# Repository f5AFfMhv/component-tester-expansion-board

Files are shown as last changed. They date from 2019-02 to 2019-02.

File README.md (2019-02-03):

# Electronic component tester expansion board

This is PCB expansion board for one of many variants of cheap electronic component testers (see picture).
<br>
[Schematic Rev A](https://github.com/f5AFfMhv/component-tester-expansion-board/raw/master/Rev%20A/component_tester_adapter.pdf)
<br>
[Schematic Rev B](https://github.com/f5AFfMhv/component-tester-expansion-board/raw/master/Rev%20B/schematic.pdf)
<br>
[BOM Rev B](https://raw.githubusercontent.com/f5AFfMhv/component-tester-expansion-board/master/Rev%20B/component_tester_adapter.csv)

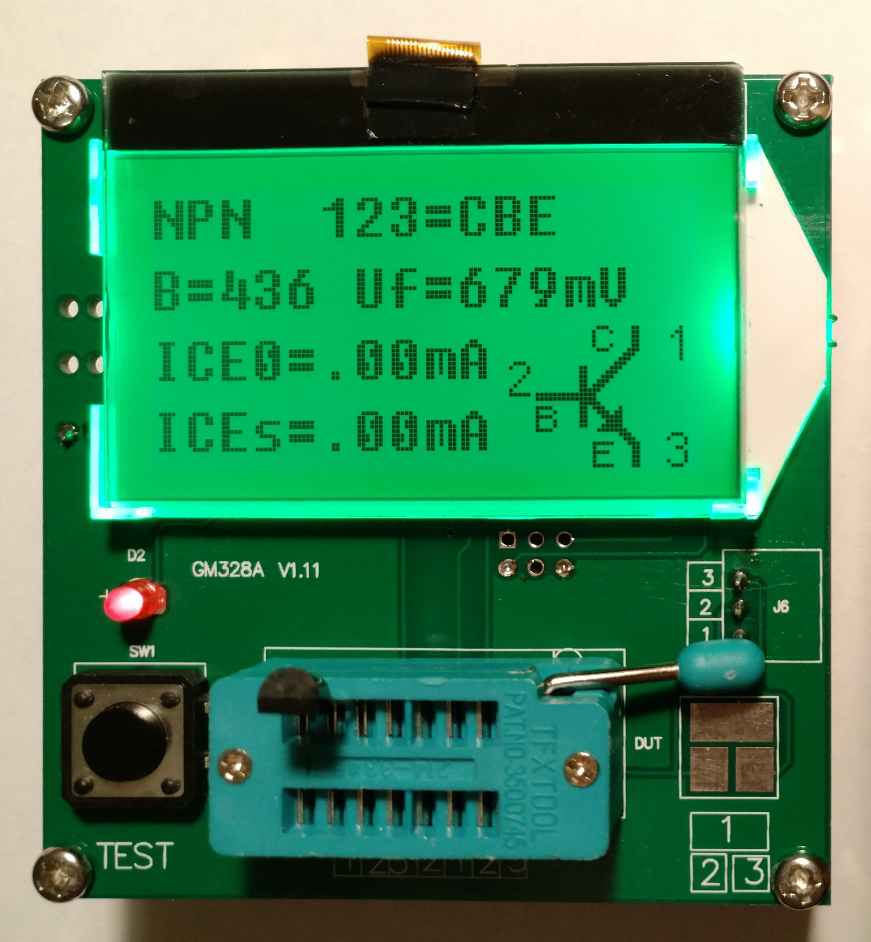
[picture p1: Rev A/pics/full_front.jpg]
Full front


## Features

<ul>
  <li>LiPO battery replaces 9V battery.</li>
  <li>1 cell LiPO charger with microUSB connector.</li>
  <li>Adjustable low battery voltage indicator.</li>
</ul>

## Rev B

<ul>
  <li>Removed direct power passthrough from microUSB to MCU over ICSP connector (don't work as expected).</li>
  <li>Changed low battery voltage indicator voltage set resistors values.</li>
  <li>Changed some silkscreen text and position.</li>
</ul>

## Board pictures

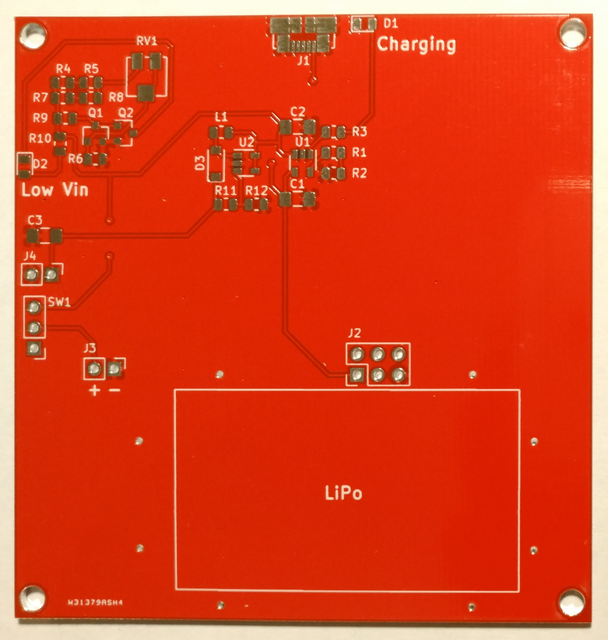
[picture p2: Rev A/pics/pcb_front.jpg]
PCB front

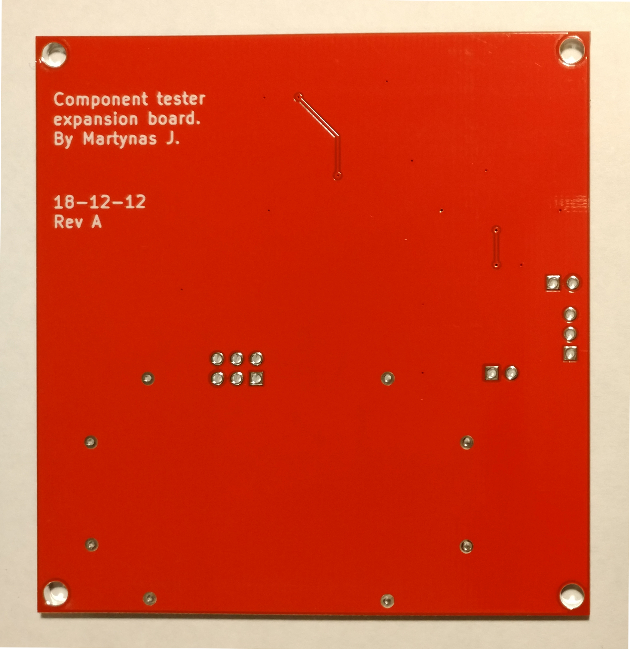
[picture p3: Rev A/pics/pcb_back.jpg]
PCB back

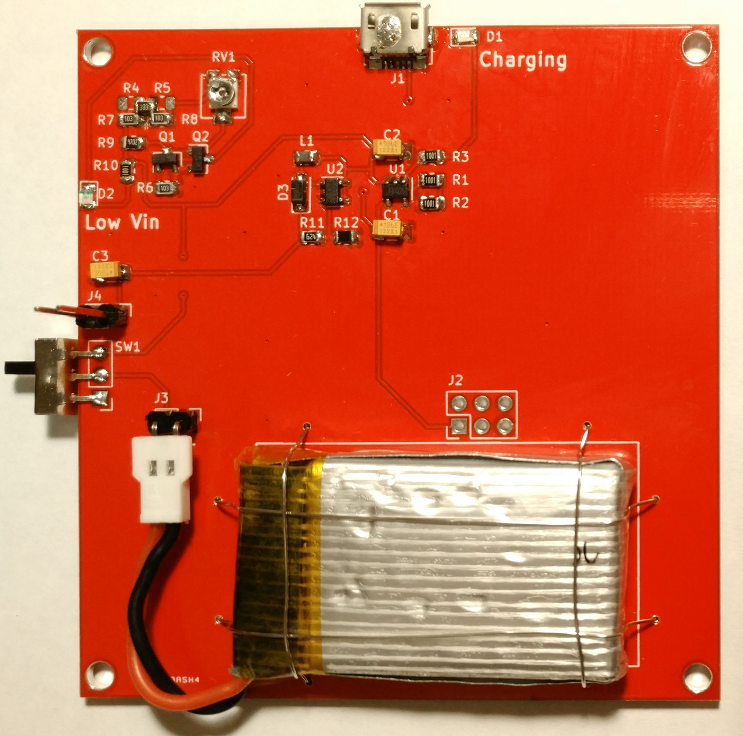
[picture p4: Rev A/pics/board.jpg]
Board

Full side

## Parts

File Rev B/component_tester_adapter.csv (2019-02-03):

Title | Component tester adapter
Revision | B
Date | 2019-02-02
Generated | 2019 m. vasario 03 d. 17:08:40
Company | Martynas J.
Comment 1
Comment 2
Comment 3
Comment 4
Total Parts | 27
Total Unique Parts | 18
Ref | Qty | Value | Footprint | Datasheet
C1 C2 C3 | 3 | 10u | Capacitor_SMD:C_1206_3216Metric_Pad1.42x1.75mm_HandSolder | ~
D1 D2 | 2 | LED | LED_SMD:LED_0805_2012Metric | ~
D3 | 1 | MBR0530 | Diode_SMD:D_SOD-123 | http://www.mccsemi.com/up_pdf/MBR0520~MBR0580(SOD123).pdf
J1 | 1 | microUSB | Connector_USB:USB_Micro-B_Molex_47346-0001 | ~
J2 | 1 | LiPo | Connector_PinHeader_2.54mm:PinHeader_1x02_P2.54mm_Vertical | ~
J3 | 1 | 9V | Connector_PinHeader_2.54mm:PinHeader_1x02_P2.54mm_Vertical | ~
L1 | 1 | 4.7u | Inductor_SMD:L_0805_2012Metric | ~
Q1 Q2 | 2 | BC847 | Package_TO_SOT_SMD:SOT-23 | http://www.infineon.com/dgdl/Infineon-BC847SERIES_BC848SERIES_BC849SERIES_BC850SERIES-DS-v01_01-en.pdf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
R1 R2 R3 R9 | 4 | 1K | Resistor_SMD:R_0805_2012Metric | ~
R4 | 1 | 33K | Resistor_SMD:R_0805_2012Metric | ~
R5 R6 R7 | 3 | 10K | Resistor_SMD:R_0805_2012Metric | ~
R8 | 1 | 47K | Resistor_SMD:R_0805_2012Metric | ~
R10 | 1 | 620K | Resistor_SMD:R_0805_2012Metric | ~
R11 | 1 | 100K | Resistor_SMD:R_0805_2012Metric | ~
RV1 | 1 | 10K | Potentiometer_SMD:Potentiometer_Bourns_3214J_Horizontal | ~
SW1 | 1 | power | Connector_PinHeader_2.54mm:PinHeader_1x03_P2.54mm_Vertical
U1 | 1 | MCP73831 | Package_TO_SOT_SMD:SOT-23-5 | http://ww1.microchip.com/downloads/en/DeviceDoc/20001984g.pdf
U2 | 1 | MCP1661 | Package_TO_SOT_SMD:SOT-23-5 | http://ww1.microchip.com/downloads/en/DeviceDoc/20005315B.pdf
BOM made with KICAD_BOM_WIZARD (https://github.com/HashDefineElectronics/KiCad_BOM_Wizard.git)
Generated 2019 m. vasario 03 d. 17:08:40

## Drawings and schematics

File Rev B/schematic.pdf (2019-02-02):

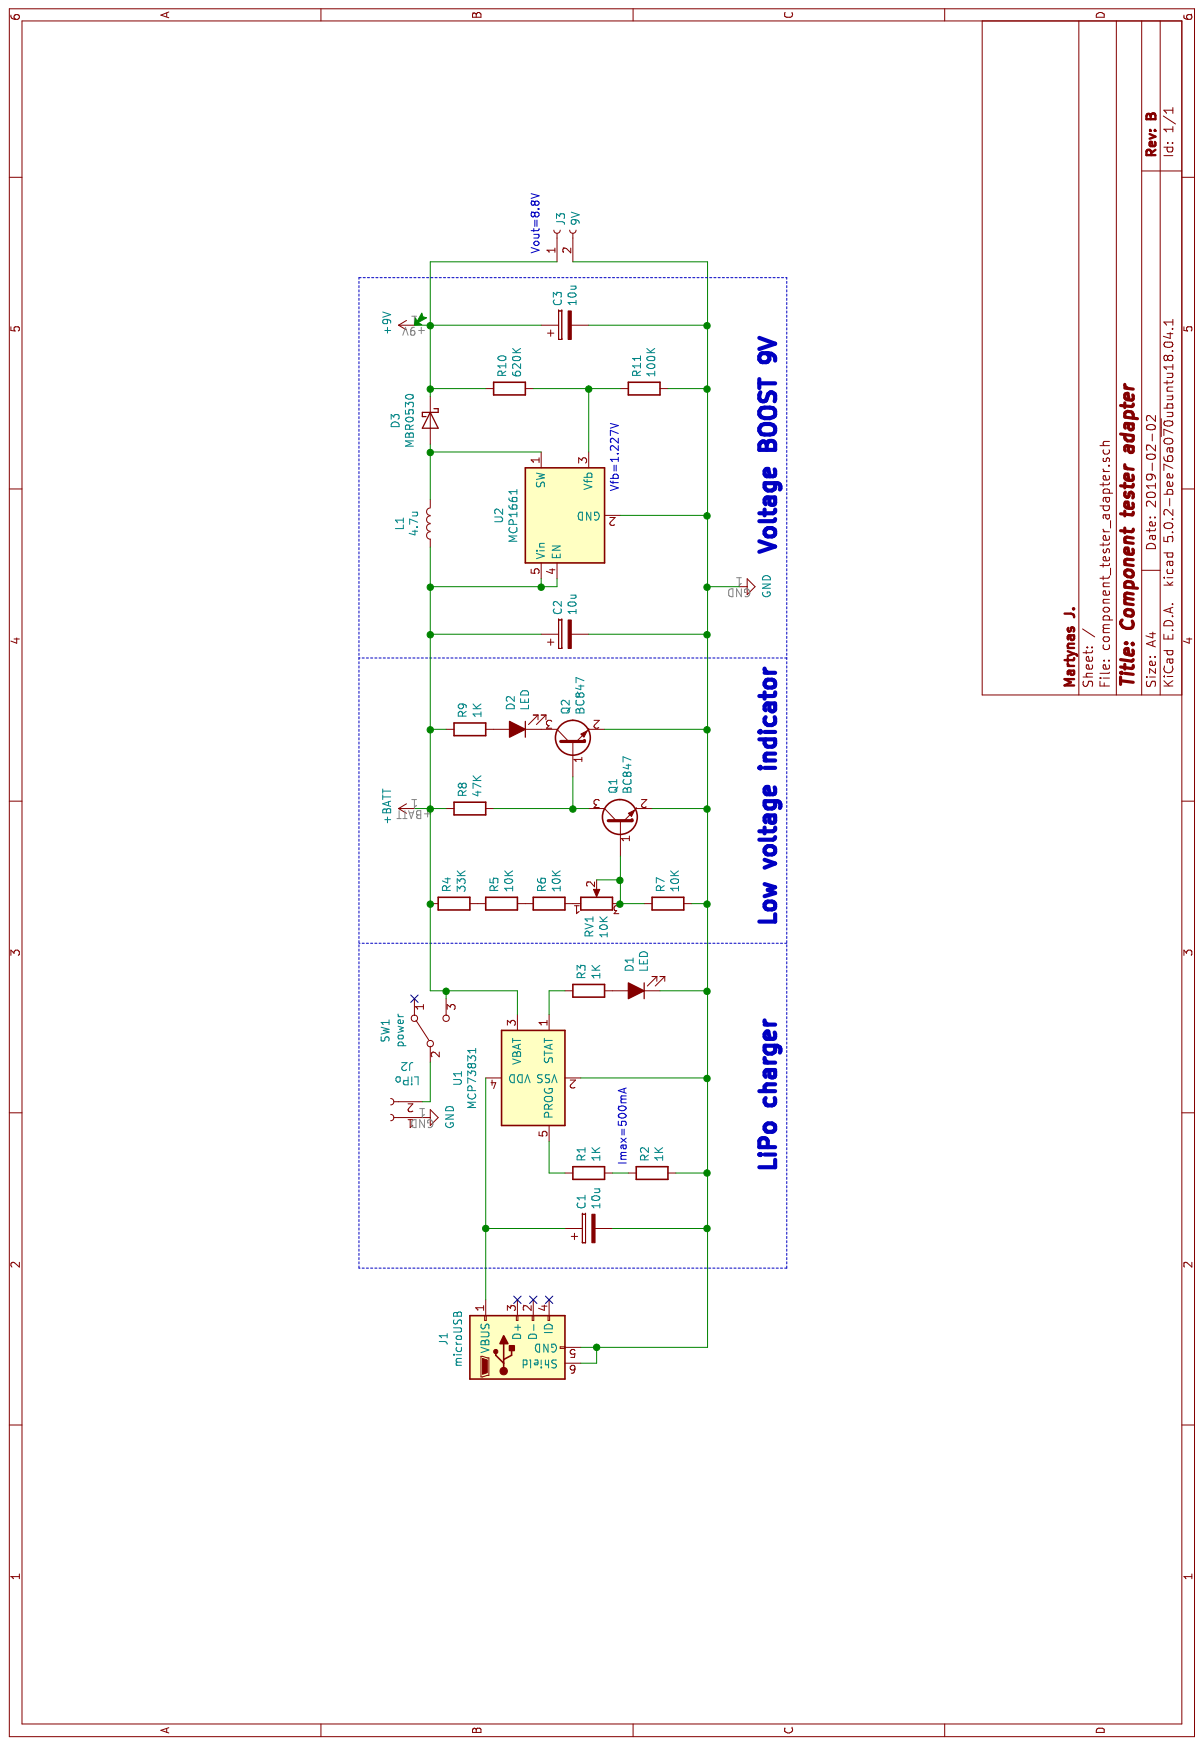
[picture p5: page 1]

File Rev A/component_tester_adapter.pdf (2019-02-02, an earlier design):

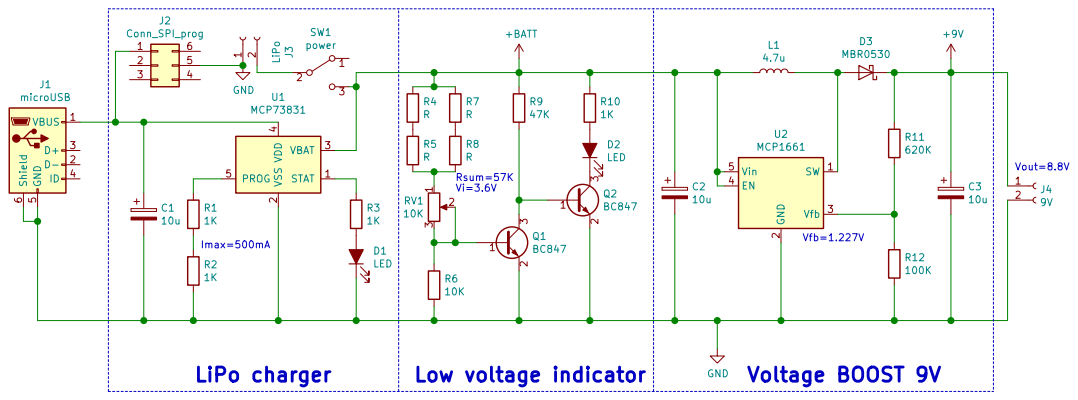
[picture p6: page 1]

File: component_tester_adapter.sch Sheet: /
Id: 1/1 Title: Component tester adapter

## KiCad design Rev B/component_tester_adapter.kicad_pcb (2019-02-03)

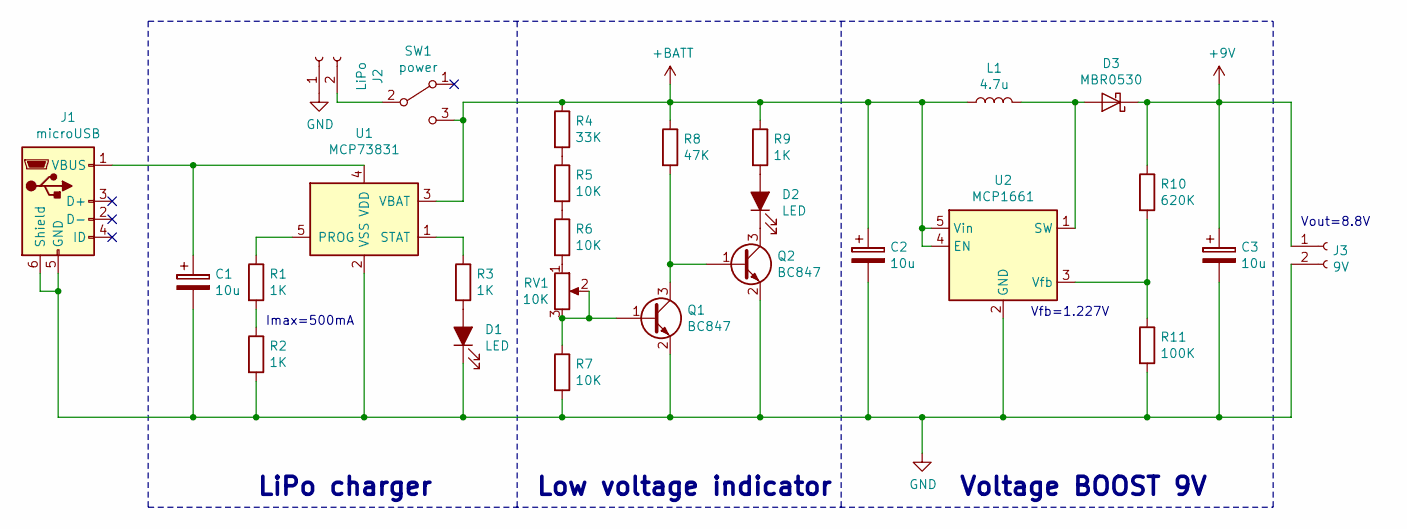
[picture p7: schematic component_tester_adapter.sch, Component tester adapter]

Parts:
C1, C2, C3: 10u; C_1206_3216Metric_Pad1.42x1.75mm_HandSolder
D1, D2: LED; LED_0805_2012Metric
D3: MBR0530; D_SOD-123
J1: microUSB; USB_Micro-B_Molex_47346-0001
J2: LiPo; PinHeader_1x02_P2.54mm_Vertical
J3: 9V; PinHeader_1x02_P2.54mm_Vertical
L1: 4.7u; L_0805_2012Metric
Q1, Q2: BC847; SOT-23
R1, R2, R3, R9: 1K; R_0805_2012Metric
R4: 33K; R_0805_2012Metric
R5, R6, R7: 10K; R_0805_2012Metric
R8: 47K; R_0805_2012Metric
R10: 620K; R_0805_2012Metric
R11: 100K; R_0805_2012Metric
RV1: 10K; Potentiometer_Bourns_3214J_Horizontal
SW1: power; PinHeader_1x03_P2.54mm_Vertical
U1: MCP73831; SOT-23-5
U2: MCP1661; SOT-23-5

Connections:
+9V: C3.1, D3.1 (K), J3.1, R10.1
+BATT: C2.1, L1.1, R4.1, R8.1, R9.1, SW1.3 (C), U1.3 (VBAT), U2.4 (EN), U2.5 (Vin)
GND: C1.2, C2.2, C3.2, D1.1 (K), J1.5 (GND), J1.6 (Shield), J2.1, J3.2, Q1.2 (E), Q2.2 (E), R2.2, R7.2, R11.2, U1.2 (VSS), U2.2 (GND)
unnamed: C1.1, J1.1 (VBUS), U1.4 (VDD)
unnamed: D1.2 (A), R3.2
unnamed: D2.1 (K), Q2.3 (C)
unnamed: D2.2 (A), R9.2
unnamed: D3.2 (A), L1.2, U2.1 (SW)
unnamed: J2.2, SW1.2 (B)
unnamed: Q1.1 (B), R7.1, RV1.2, RV1.3
unnamed: Q1.3 (C), Q2.1 (B), R8.2
unnamed: R1.1, U1.5 (PROG)
unnamed: R1.2, R2.1
unnamed: R3.1, U1.1 (STAT)
unnamed: R4.2, R5.1
unnamed: R5.2, R6.1
unnamed: R6.2, RV1.1
unnamed: R10.2, R11.1, U2.3 (Vfb)

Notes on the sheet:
Low voltage indicator
Voltage BOOST 9V
LiPo charger
Imax=500mA
Vfb=1.227V
Vout=8.8V

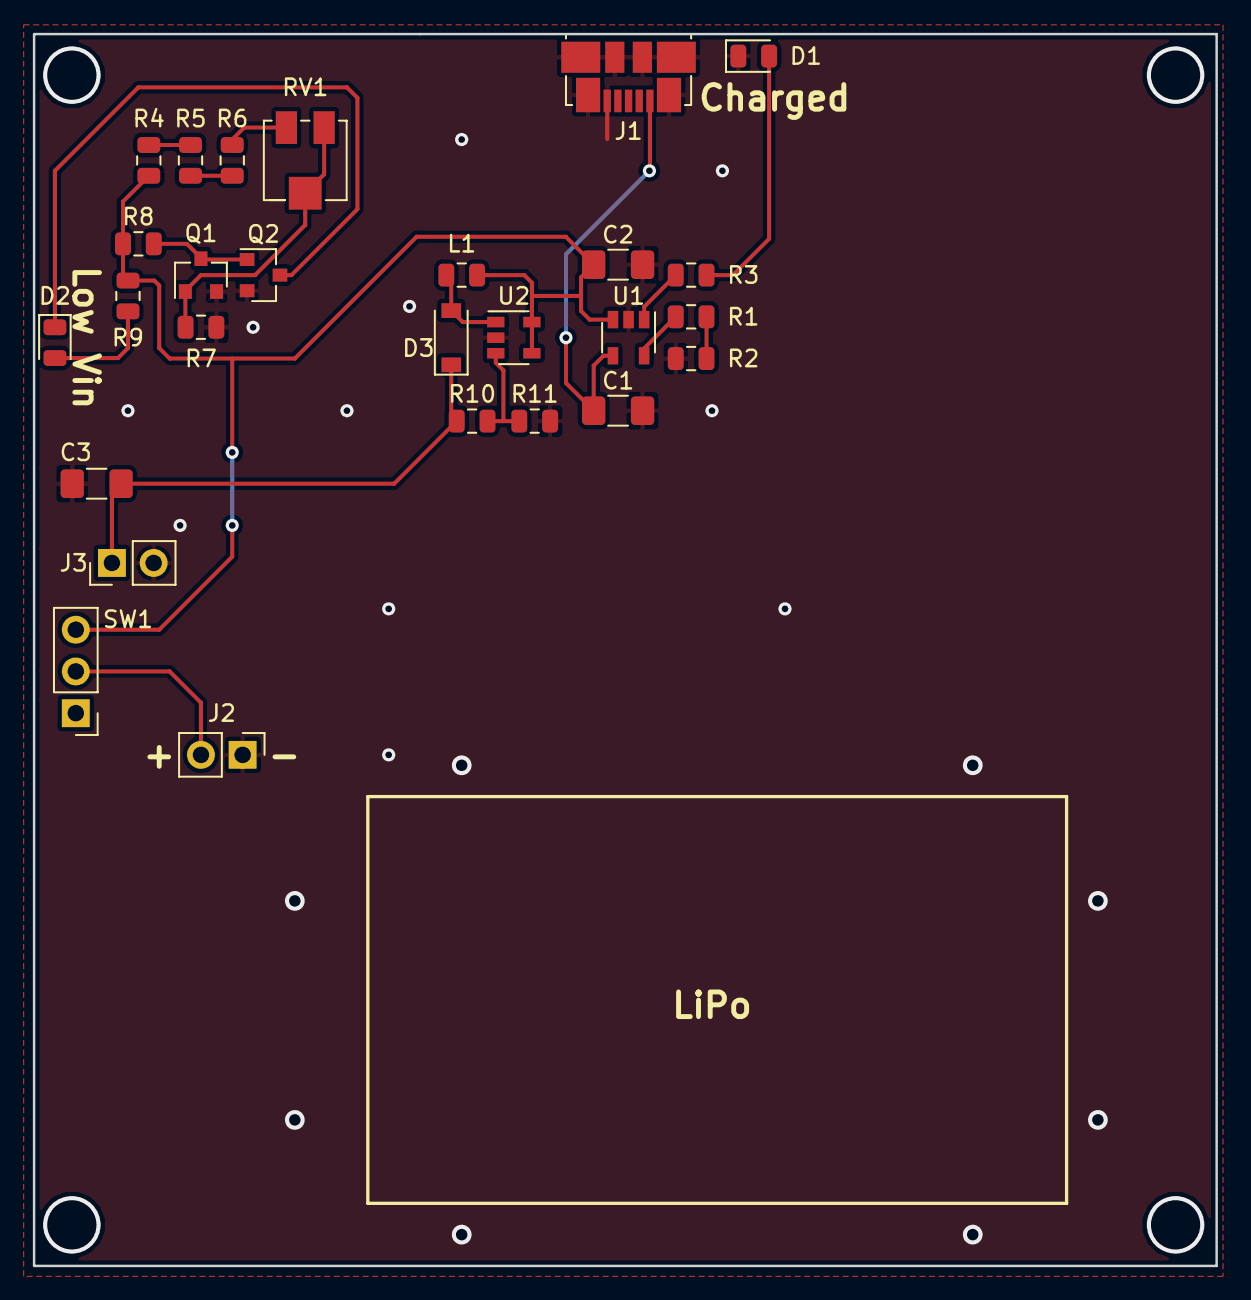
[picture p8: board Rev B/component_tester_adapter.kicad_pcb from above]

Board: 2 copper layers, 72.0 x 75.0 mm, 27 parts (0 on the bottom side), 18 nets.

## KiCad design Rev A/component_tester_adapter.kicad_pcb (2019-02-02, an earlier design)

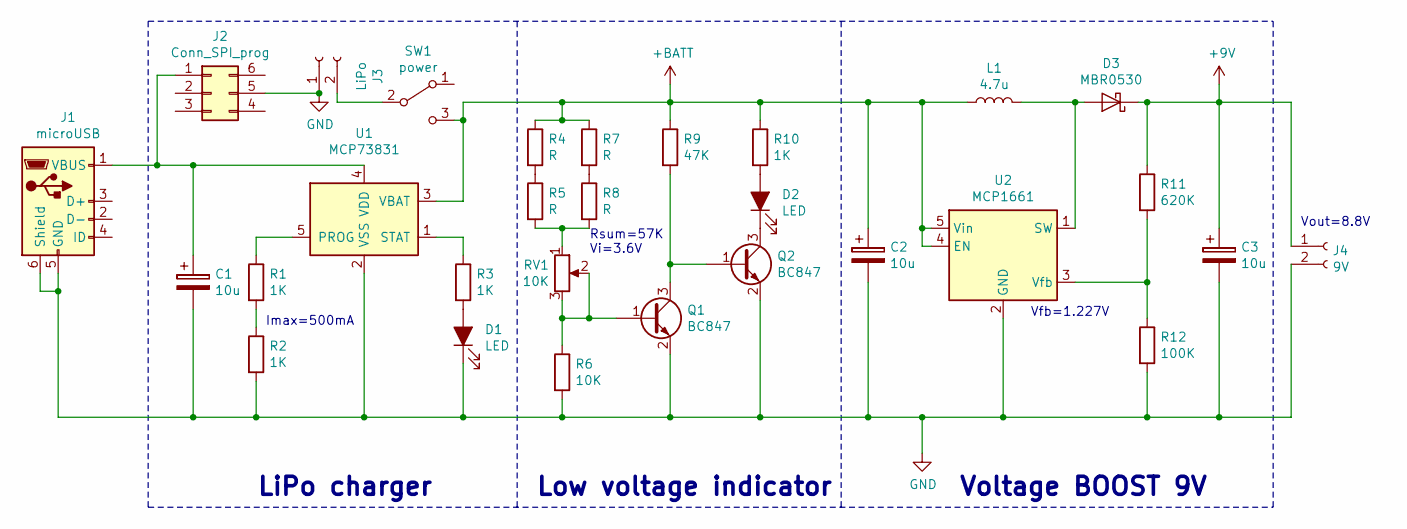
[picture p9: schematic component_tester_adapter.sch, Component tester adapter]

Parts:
C1, C2, C3: 10u; C_1206_3216Metric_Pad1.42x1.75mm_HandSolder
D1, D2: LED; LED_0805_2012Metric
D3: MBR0530; D_SOD-123
J1: microUSB; USB_Micro-B_Molex_47346-0001
J2: Conn_SPI_prog; PinHeader_2x03_P2.54mm_Vertical
J3: LiPo; PinHeader_1x02_P2.54mm_Vertical
J4: 9V; PinHeader_1x02_P2.54mm_Vertical
L1: 4.7u; L_0805_2012Metric
Q1, Q2: BC847; SOT-23
R1, R2, R3, R10: 1K; R_0805_2012Metric
R4, R5, R7, R8: R; R_0805_2012Metric
R6: 10K; R_0805_2012Metric
R9: 47K; R_0805_2012Metric
R11: 620K; R_0805_2012Metric
R12: 100K; R_0805_2012Metric
RV1: 10K; Potentiometer_Bourns_3214J_Horizontal
SW1: power; PinHeader_1x03_P2.54mm_Vertical
U1: MCP73831; SOT-23-5
U2: MCP1661; SOT-23-5

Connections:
+9V: C3.1, D3.1 (K), J4.1, R11.1
+BATT: C2.1, L1.1, R4.1, R7.1, R9.1, R10.1, SW1.3 (C), U1.3 (VBAT), U2.4 (EN), U2.5 (Vin)
GND: C1.2, C2.2, C3.2, D1.1 (K), J1.5 (GND), J1.6 (Shield), J2.5, J3.1, J4.2, Q1.2 (E), Q2.2 (E), R2.2, R6.2, R12.2, U1.2 (VSS), U2.2 (GND)
unnamed: C1.1, J1.1 (VBUS), J2.1, U1.4 (VDD)
unnamed: D1.2 (A), R3.2
unnamed: D2.1 (K), Q2.3 (C)
unnamed: D2.2 (A), R10.2
unnamed: D3.2 (A), L1.2, U2.1 (SW)
unnamed: J3.2, SW1.2 (B)
unnamed: Q1.1 (B), R6.1, RV1.2, RV1.3
unnamed: Q1.3 (C), Q2.1 (B), R9.2
unnamed: R1.1, U1.5 (PROG)
unnamed: R1.2, R2.1
unnamed: R3.1, U1.1 (STAT)
unnamed: R4.2, R5.1
unnamed: R5.2, R8.2, RV1.1
unnamed: R7.2, R8.1
unnamed: R11.2, R12.1, U2.3 (Vfb)

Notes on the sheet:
Low voltage indicator
Voltage BOOST 9V
LiPo charger
Imax=500mA
Rsum=57K Vi=3.6V
Vfb=1.227V
Vout=8.8V

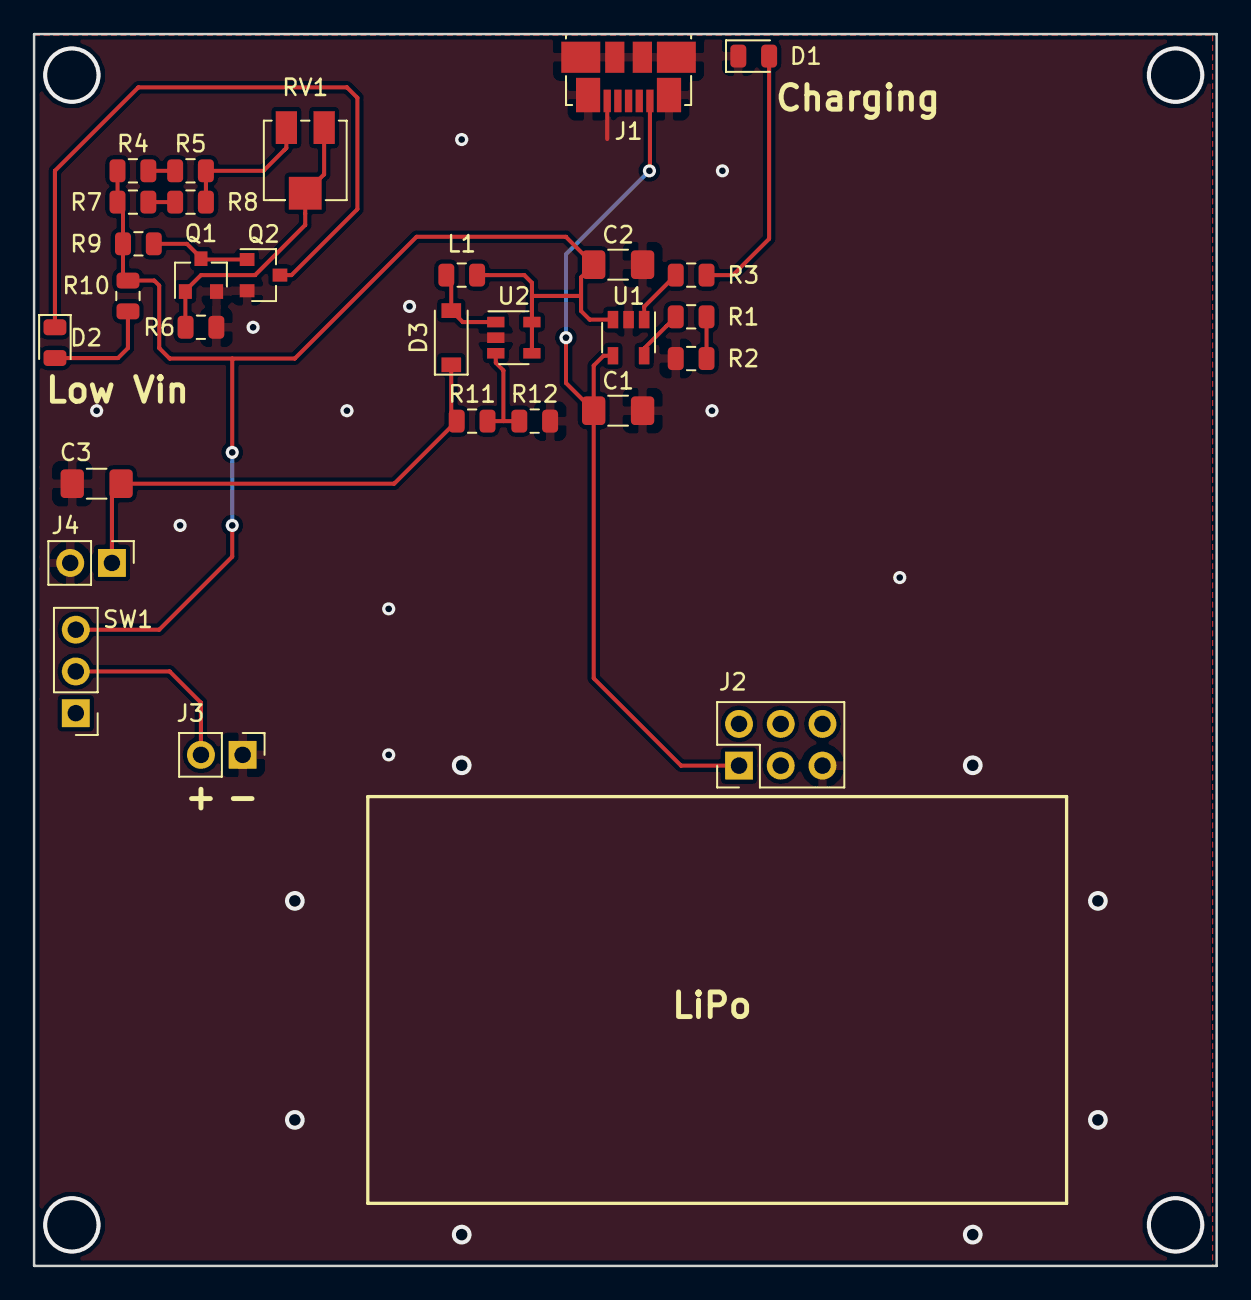
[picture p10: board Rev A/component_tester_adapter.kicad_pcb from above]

Board: 2 copper layers, 72.0 x 75.0 mm, 29 parts (0 on the bottom side), 18 nets.

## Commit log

2019-02-03 added REV B
    [component_tester_adapter-B.Cu.gbr, component_tester_adapter-B.Mask.gbr, component_tester_adapter-B.SilkS.gbr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]
2019-02-03 added BOM
    [component_tester_adapter.csv]
